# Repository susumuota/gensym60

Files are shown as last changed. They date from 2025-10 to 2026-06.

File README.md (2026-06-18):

# gensym60

A redesign of the symmetrical 60% keyboard.

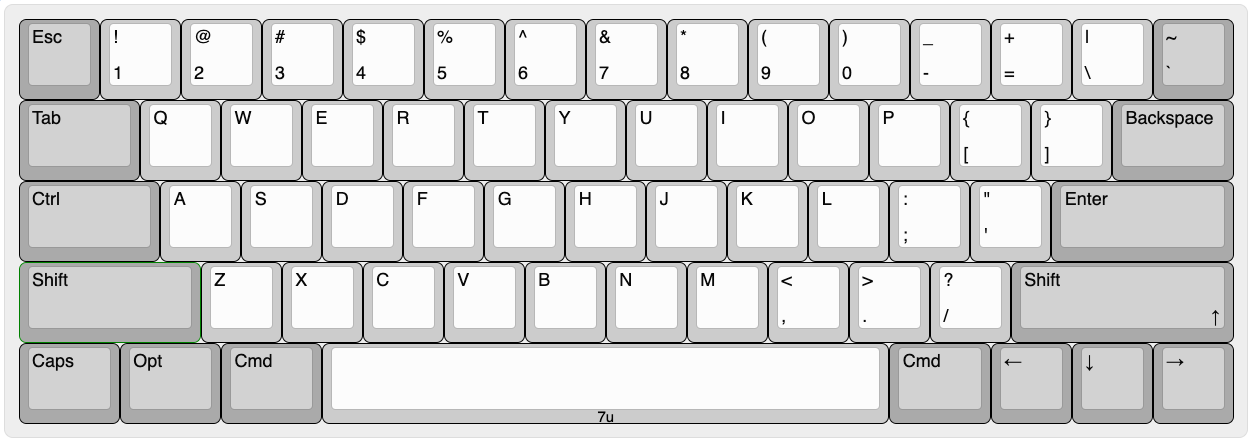
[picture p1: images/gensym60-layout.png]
layout


- 60% layout
- 7u space bar
- Split backspace
- Arrow keys (Up is mod-tap on the right shift)
- No split right shift

## Build firmware

```shell
git clone https://github.com/susumuota/gensym60.git

git clone https://github.com/vial-kb/vial-qmk.git
cd vial-qmk

# copy gensym60 directory to vial-qmk
rsync -av --delete ../gensym60/vial-qmk/keyboards/infinitemonkey/gensym60/ keyboards/infinitemonkey/gensym60/

RUNTIME="docker" SKIP_FLASHING_SUPPORT=1 util/docker_cmd.sh make infinitemonkey/gensym60:vial

ls -l infinitemonkey_gensym60_vial.bin
# -rwxr-xr-x 1 user group 37072 Jun 18 01:23 infinitemonkey_gensym60_vial.bin
```

## Flash firmware

Install `dfu-util` package.

```shell
brew install dfu-util
```

```shell
# unplug and plug the device pressing the dfu button
dfu-util -l
sudo dfu-util -a 0 -s 0x08000000:unprotect:force

# unplug and plug the device pressing the dfu button
dfu-util -l
sudo dfu-util -a 0 -s 0x08000000:mass-erase:force

# unplug and plug the device pressing the dfu button
dfu-util -l
sudo dfu-util -a 0 -s 0x08000000:leave -D infinitemonkey_gensym60_vial.bin
```

## References

- https://github.com/Unified-Daughterboard/UDB-C-JSH
- https://github.com/kkatano/bakeneko-60
- https://github.com/takishim/mikeneko65
- https://github.com/tominabox1/Le-Chiffre-Keyboard
- https://github.com/sporkus/le_chiffre_keyboard_stm32
- https://github.com/joe-scotto/scottokeebs/tree/main/Extras/ScottoModules/STM32F072CBT6
- https://www.st.com/resource/en/application_note/an4080-getting-started-with-stm32f0x1x2x8-hardware-development-stmicroelectronics.pdf
- https://www.st.com/en/evaluation-tools/32f072bdiscovery.html
- https://microfan.shop/products/stm32f072-mini-r1
- https://github.com/ShaneTWilliams/stm32-dev-board
- https://github.com/bennymeg/Fabrication-Toolkit
- https://github.com/Salicylic-acid3/KiCAD_FootPrint

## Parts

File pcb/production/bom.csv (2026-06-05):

Designator | Footprint | Quantity | Value | LCSC Part #
C1, C2, C9 | 0402 | 3 | 1u | C52923
C10, C12, C3, C4, C6, C7, C8 | 0402 | 7 | 100n | C1525
C11, C5 | 0402 | 2 | 4.7u | C23733
D1, D10, D11, D12, D13, D14, D15, D16, D17, D18, D19, D2, D20, D21, D22, D23, D24, D25, D26, D27, D28, D29, D3, D30, D31, D32, D33, D34, D35, D36, D37, D38, D39, D4, D40, D41, D42, D43, D44, D45, D46, D47, D48, D49, D5, D50, D51, D52, D53, D54, D55, D56, D57, D58, D59, D6, D60, D61, D62, D7, D8, D9 | D_SOD-123 | 62 | 1N4148W | C81598
F1 | 1206 | 1 | ASMD1206-050 | C135338
J1 | JST_SH_SM04B-SRSS-TB_1x04-1MP_P1.00mm_Horizontal | 1 | JST-SH | C160404
R1 | 0402 | 1 | 10k | C25744
SMDSW1 | SW_Push_1P1T_XKB_TS-1187A | 1 | TS-1187A-B-A-B | C318884
SW1, SW10, SW12, SW13, SW14, SW16, SW17, SW18, SW19, SW20, SW21, SW22, SW23, SW24, SW25, SW26, SW27, SW28, SW29, SW30, SW31, SW32, SW33, SW34, SW35, SW37, SW38, SW39, SW40, SW41, SW42, SW43, SW44, SW45, SW46, SW47, SW48, SW49, SW50, SW51, SW52, SW54, SW55, SW56, SW57, SW6, SW61, SW62, SW7, SW8, SW9 | CherryMX_Hotswap_1u | 51 | SW_Push | C41430893
SW11, SW15, SW5, SW53 | CherryMX_Hotswap_1.25u | 4 | SW_Push | C41430893
SW2, SW58 | CherryMX_Hotswap_1.5u | 2 | SW_Push | C41430893
SW3 | CherryMX_Hotswap_1.75u | 1 | SW_Push | C41430893
SW36 | CherryMX_Hotswap_7u_Rev | 1 | SW_Push | C41430893
SW4, SW59 | CherryMX_Hotswap_2.25u | 2 | SW_Push | C41430893
SW60 | CherryMX_Hotswap_2.75u | 1 | SW_Push | C41430893
U1 | SOT-23-3 | 1 | XC6206P332MR-G | C5446
U2 | LQFP-48_7x7mm_P0.5mm | 1 | STM32F072CBT6 | C81720
U3 | SOT-23-6 | 1 | USBLC6-2SC6 | C7519

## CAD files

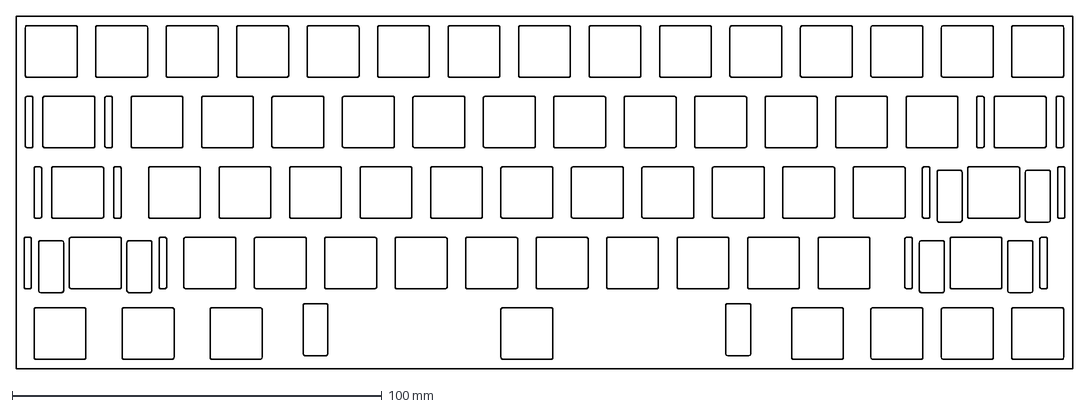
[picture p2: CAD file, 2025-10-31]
plate/gensym60_plate.dxf
285.8 x 95.2 mm

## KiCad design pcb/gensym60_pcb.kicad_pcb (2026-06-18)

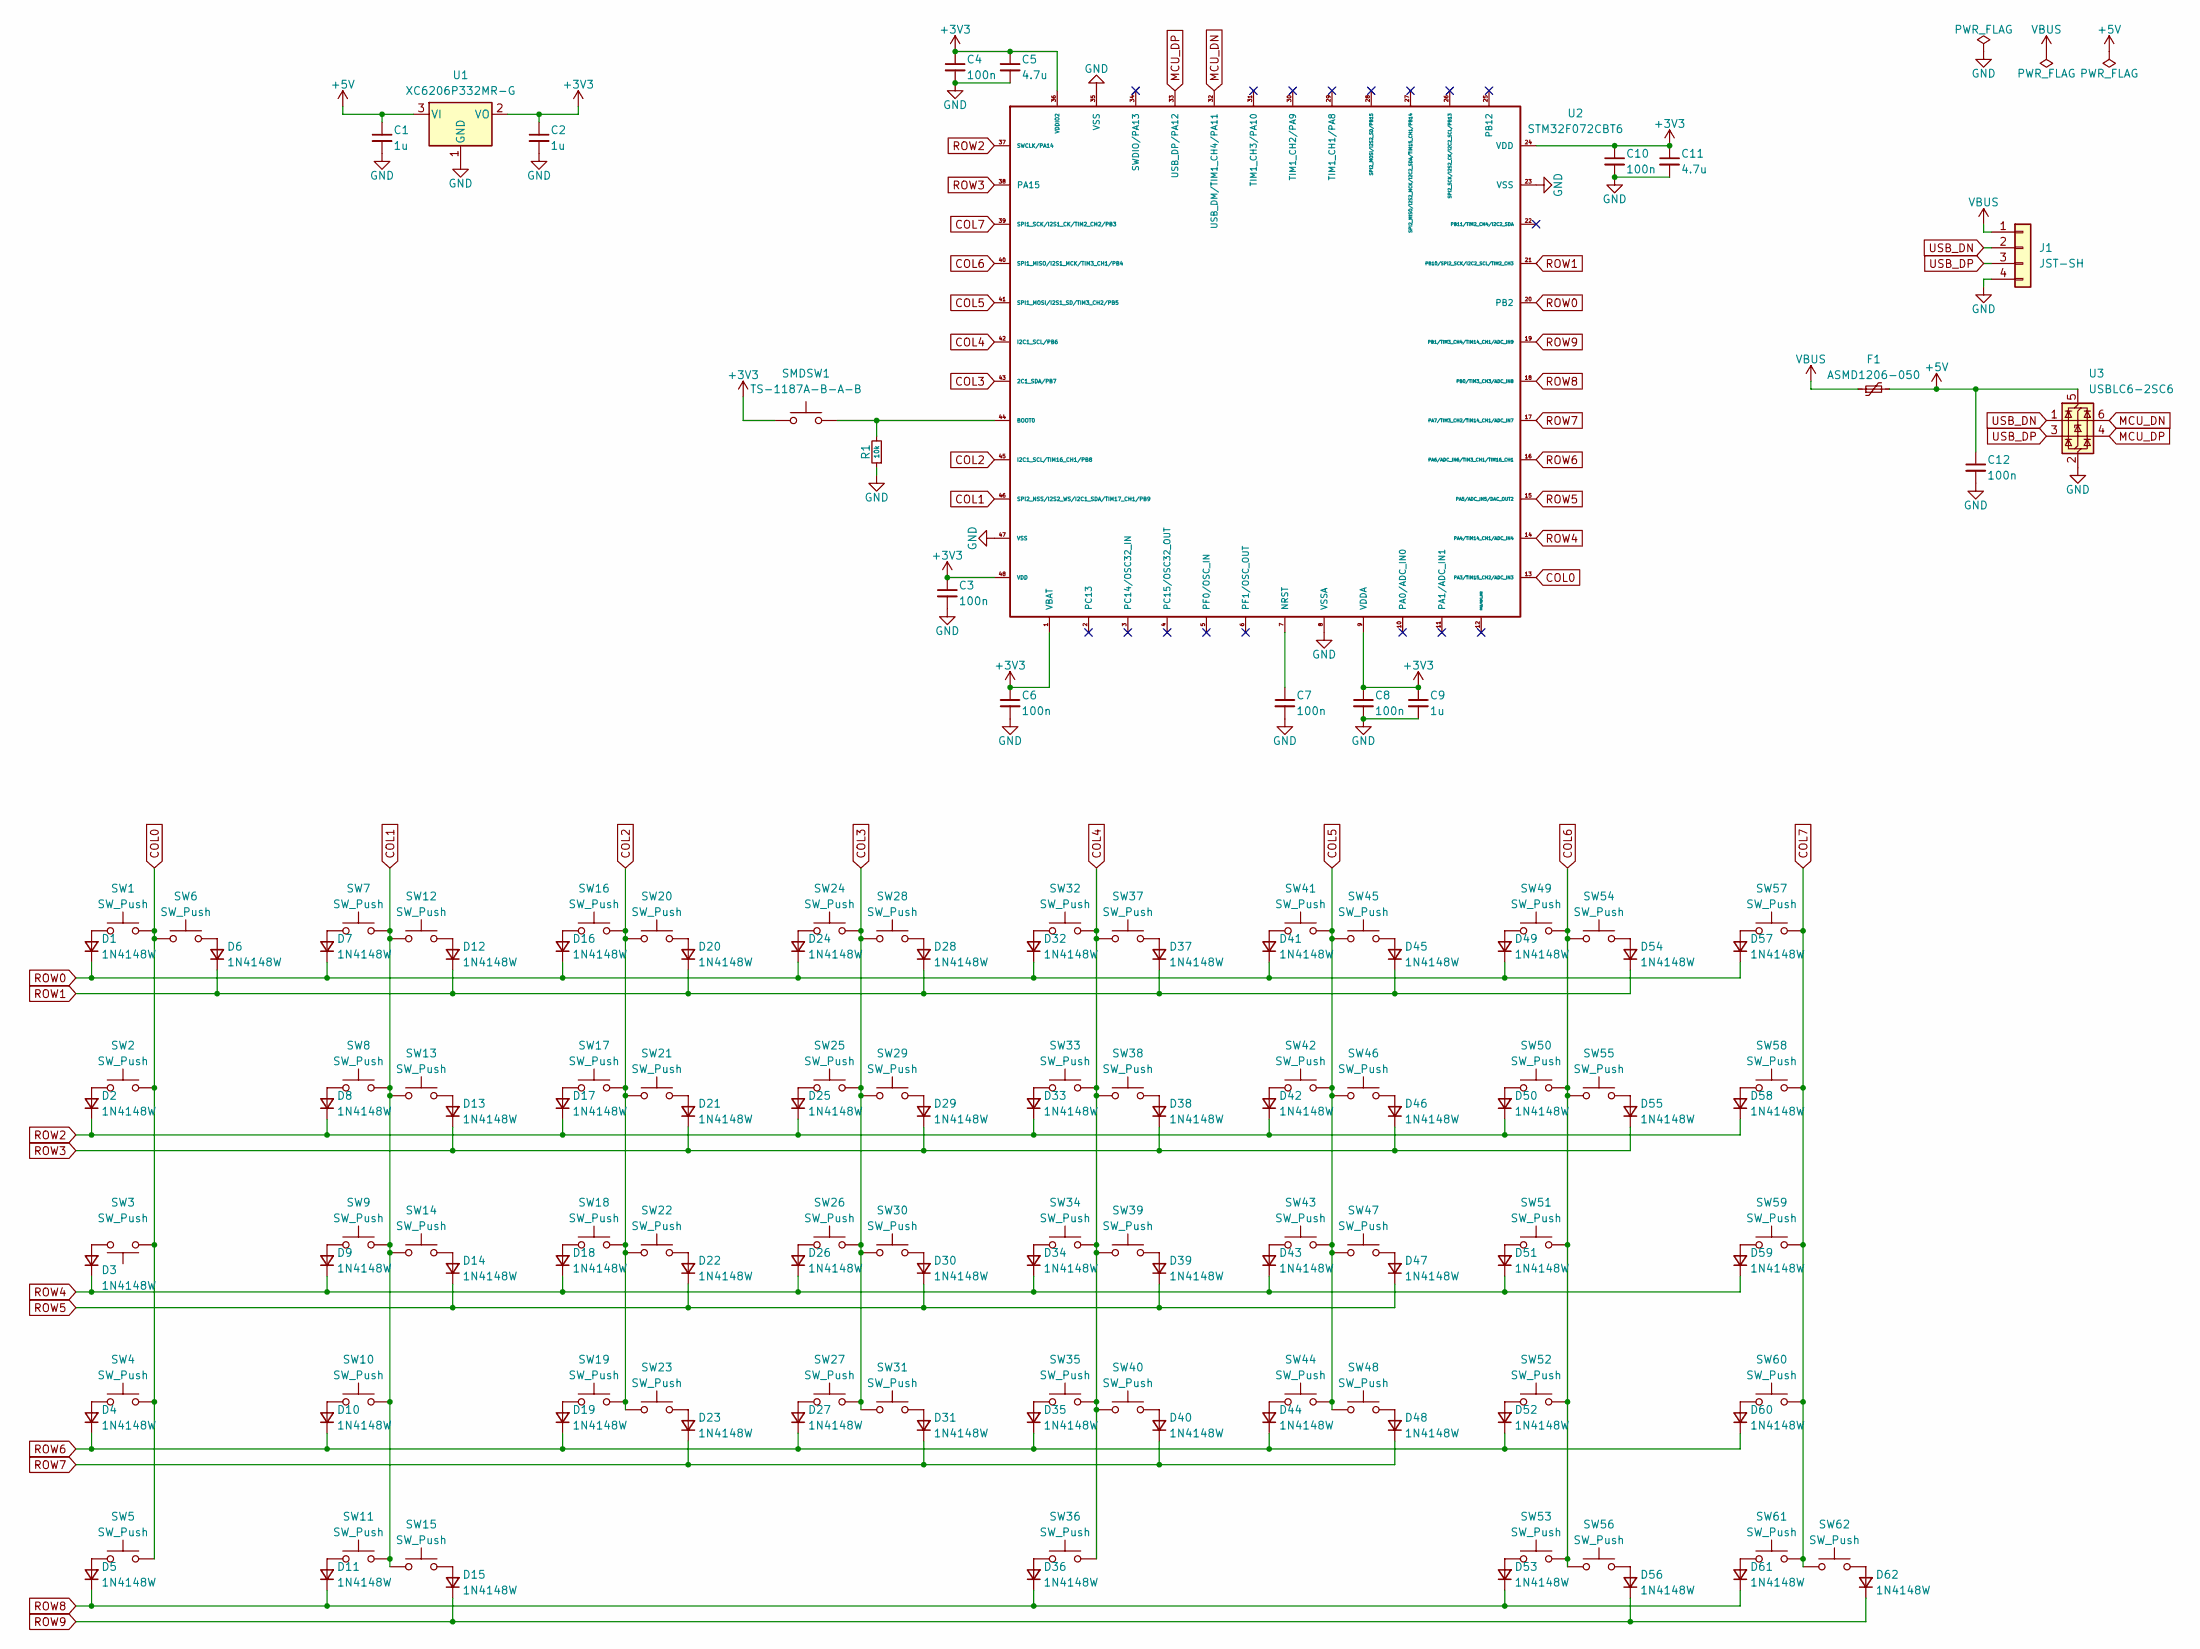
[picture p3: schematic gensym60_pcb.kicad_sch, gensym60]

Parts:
C1, C2, C9: 1u; C_0402_1005Metric; MFR.Part # CL05A105KA5NQNC; LCSC PN C52923
C3, C4, C6, C7, C8, C10, C12: 100n; C_0402_1005Metric; MFR.Part # CL05B104KO5NNNC; LCSC PN C1525
C5, C11: 4.7u; C_0402_1005Metric; MFR.Part # CL05A475MP5NRNC; LCSC PN C23733
D1, D2, D3, D4, D5, D6, D7, D8, D9, D10, D11, D12, D13, D14, D15, D16, D17, D18, D19, D20, D21, D22, D23, D24, D25, D26, D27, D28, D29, D30, D31, D32, D33, D34, D35, D36, D37, D38, D39, D40, D41, D42, D43, D44, D45, D46, D47, D48, D49, D50, D51, D52, D53, D54, D55, D56, D57, D58, D59, D60, D61, D62: 1N4148W; D_SOD-123; MFR.Part # 1N4148W; LCSC PN C81598
F1: ASMD1206-050; Fuse_1206_3216Metric; MFR.Part # ASMD1206-050; LCSC PN C135338
J1: JST-SH; JST_SH_SM04B-SRSS-TB_1x04-1MP_P1.00mm_Horizontal; MFR.Part # SM04B-SRSS-TB(LF)(SN); LCSC PN C160404
R1: 10k; R_0402_1005Metric; MFR.Part # 0402WGF1002TCE; LCSC PN C25744
SMDSW1: TS-1187A-B-A-B; SW_Push_1P1T_XKB_TS-1187A; MFR.Part # TS-1187A-B-A-B; LCSC PN C318884
SW1, SW6, SW7, SW8, SW9, SW10, SW12, SW13, SW14, SW16, SW17, SW18, SW19, SW20, SW21, SW22, SW23, SW24, SW25, SW26, SW27, SW28, SW29, SW30, SW31, SW32, SW33, SW34, SW35, SW37, SW38, SW39, SW40, SW41, SW42, SW43, SW44, SW45, SW46, SW47, SW48, SW49, SW50, SW51, SW52, SW54, SW55, SW56, SW57, SW61, SW62: SW_Push; CherryMX_Hotswap_1u; MFR.Part # CPG151101S11-16; LCSC PN C41430893
SW2, SW58: SW_Push; CherryMX_Hotswap_1.5u; MFR.Part # CPG151101S11-16; LCSC PN C41430893
SW3: SW_Push; CherryMX_Hotswap_1.75u; MFR.Part # CPG151101S11-16; LCSC PN C41430893
SW4, SW59: SW_Push; CherryMX_Hotswap_2.25u; MFR.Part # CPG151101S11-16; LCSC PN C41430893
SW5, SW11, SW15, SW53: SW_Push; CherryMX_Hotswap_1.25u; MFR.Part # CPG151101S11-16; LCSC PN C41430893
SW36: SW_Push; CherryMX_Hotswap_7u_Rev; MFR.Part # CPG151101S11-16; LCSC PN C41430893
SW60: SW_Push; CherryMX_Hotswap_2.75u; MFR.Part # CPG151101S11-16; LCSC PN C41430893
U1: XC6206P332MR-G; SOT-23-3; MFR.Part # XC6206P332MR-G; LCSC PN C5446
U2: STM32F072CBT6; LQFP-48_7x7mm_P0.5mm; MFR.Part # STM32F072CBT6; LCSC PN C81720
U3: USBLC6-2SC6; SOT-23-6; MFR.Part # USBLC6-2SC6; LCSC PN C7519

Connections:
+3V3: C2.1, C3.1, C4.1, C5.1, C6.1, C8.1, C9.1, C10.1, C11.1, SMDSW1.1, U1.2 (VO), U2.1 (VBAT), U2.9 (VDDA), U2.24 (VDD), U2.36 (VDDIO2), U2.48 (VDD)
+5V: C1.1, C12.1, F1.2, U1.3 (VI), U3.5 (VBUS)
COL0: SW1.2, SW2.2, SW3.1, SW4.2, SW5.2, SW6.1, U2.13 (PA3/TIM15_CH2/ADC_IN3)
COL1: SW7.2, SW8.2, SW9.2, SW10.2, SW11.2, SW12.1, SW13.1, SW14.1, SW15.1, U2.46 (SPI2_NSS/I2S2_WS/I2C1_SDA/TIM17_CH1/PB9)
COL2: SW16.2, SW17.2, SW18.2, SW19.2, SW20.1, SW21.1, SW22.1, SW23.1, U2.45 (I2C1_SCL/TIM16_CH1/PB8)
COL3: SW24.2, SW25.2, SW26.2, SW27.2, SW28.1, SW29.1, SW30.1, SW31.1, U2.43 (2C1_SDA/PB7)
COL4: SW32.2, SW33.2, SW34.2, SW35.2, SW36.2, SW37.1, SW38.1, SW39.1, SW40.1, U2.42 (I2C1_SCL/PB6)
COL5: SW41.2, SW42.2, SW43.2, SW44.2, SW45.1, SW46.1, SW47.1, SW48.1, U2.41 (SPI1_MOSI/I2S1_SD/TIM3_CH2/PB5)
COL6: SW49.2, SW50.2, SW51.2, SW52.2, SW53.2, SW54.1, SW55.1, SW56.1, U2.40 (SPI1_MISO/I2S1_MCK/TIM3_CH1/PB4)
COL7: SW57.2, SW58.2, SW59.2, SW60.2, SW61.2, SW62.1, U2.39 (SPI1_SCK/I2S1_CK/TIM2_CH2/PB3)
GND: C1.2, C2.2, C3.2, C4.2, C5.2, C6.2, C7.2, C8.2, C9.2, C10.2, C11.2, C12.2, J1.4, R1.1, U1.1 (GND), U2.8 (VSSA), U2.23 (VSS), U2.35 (VSS), U2.47 (VSS), U3.2 (GND)
MCU_DN: U2.32 (USB_DM/TIM1_CH4/PA11), U3.6 (I/O1)
MCU_DP: U2.33 (USB_DP/PA12), U3.4 (I/O2)
unnamed: D1.2 (A), SW1.1
unnamed: D2.2 (A), SW2.1
unnamed: D3.2 (A), SW3.2
unnamed: D4.2 (A), SW4.1
unnamed: D5.2 (A), SW5.1
unnamed: D6.2 (A), SW6.2
unnamed: D7.2 (A), SW7.1
unnamed: D8.2 (A), SW8.1
unnamed: D9.2 (A), SW9.1
unnamed: D10.2 (A), SW10.1
unnamed: D11.2 (A), SW11.1
unnamed: D12.2 (A), SW12.2
unnamed: D13.2 (A), SW13.2
unnamed: D14.2 (A), SW14.2
unnamed: D15.2 (A), SW15.2
unnamed: D16.2 (A), SW16.1
unnamed: D17.2 (A), SW17.1
unnamed: D18.2 (A), SW18.1
unnamed: D19.2 (A), SW19.1
unnamed: D20.2 (A), SW20.2
unnamed: D21.2 (A), SW21.2
unnamed: D22.2 (A), SW22.2
unnamed: D23.2 (A), SW23.2
unnamed: D24.2 (A), SW24.1
unnamed: D25.2 (A), SW25.1
unnamed: D26.2 (A), SW26.1
unnamed: D27.2 (A), SW27.1
unnamed: D28.2 (A), SW28.2
unnamed: D29.2 (A), SW29.2
unnamed: D30.2 (A), SW30.2
unnamed: D31.2 (A), SW31.2
unnamed: D32.2 (A), SW32.1
unnamed: D33.2 (A), SW33.1
unnamed: D34.2 (A), SW34.1
unnamed: D35.2 (A), SW35.1
unnamed: D36.2 (A), SW36.1
unnamed: D37.2 (A), SW37.2
unnamed: D38.2 (A), SW38.2
unnamed: D39.2 (A), SW39.2
unnamed: D40.2 (A), SW40.2
unnamed: D41.2 (A), SW41.1
unnamed: D42.2 (A), SW42.1
unnamed: D43.2 (A), SW43.1
unnamed: D44.2 (A), SW44.1
unnamed: D45.2 (A), SW45.2
unnamed: D46.2 (A), SW46.2
unnamed: D47.2 (A), SW47.2
unnamed: D48.2 (A), SW48.2
unnamed: D49.2 (A), SW49.1
unnamed: D50.2 (A), SW50.1
unnamed: D51.2 (A), SW51.1
unnamed: D52.2 (A), SW52.1
unnamed: D53.2 (A), SW53.1
unnamed: D54.2 (A), SW54.2
unnamed: D55.2 (A), SW55.2
unnamed: D56.2 (A), SW56.2
unnamed: D57.2 (A), SW57.1
unnamed: D58.2 (A), SW58.1
unnamed: D59.2 (A), SW59.1
unnamed: D60.2 (A), SW60.1
unnamed: D61.2 (A), SW61.1
unnamed: D62.2 (A), SW62.2
unnamed: R1.2, SMDSW1.2, U2.44 (BOOT0)
unnamed: C7.1, U2.7 (NRST)
ROW0: D1.1 (K), D7.1 (K), D16.1 (K), D24.1 (K), D32.1 (K), D41.1 (K), D49.1 (K), D57.1 (K), U2.20 (PB2)
ROW1: D6.1 (K), D12.1 (K), D20.1 (K), D28.1 (K), D37.1 (K), D45.1 (K), D54.1 (K), U2.21 (PB10/SPI2_SCK/I2C2_SCL/TIM2_CH3)
ROW2: D2.1 (K), D8.1 (K), D17.1 (K), D25.1 (K), D33.1 (K), D42.1 (K), D50.1 (K), D58.1 (K), U2.37 (SWCLK/PA14)
ROW3: D13.1 (K), D21.1 (K), D29.1 (K), D38.1 (K), D46.1 (K), D55.1 (K), U2.38 (PA15)
ROW4: D3.1 (K), D9.1 (K), D18.1 (K), D26.1 (K), D34.1 (K), D43.1 (K), D51.1 (K), D59.1 (K), U2.14 (PA4/TIM14_CH1/ADC_IN4)
ROW5: D14.1 (K), D22.1 (K), D30.1 (K), D39.1 (K), D47.1 (K), U2.15 (PA5/ADC_IN5/DAC_OUT2)
ROW6: D4.1 (K), D10.1 (K), D19.1 (K), D27.1 (K), D35.1 (K), D44.1 (K), D52.1 (K), D60.1 (K), U2.16 (PA6/ADC_IN6/TIM3_CH1/TIM16_CH1)
ROW7: D23.1 (K), D31.1 (K), D40.1 (K), D48.1 (K), U2.17 (PA7/TIM3_CH2/TIM14_CH1/ADC_IN7)
ROW8: D5.1 (K), D11.1 (K), D36.1 (K), D53.1 (K), D61.1 (K), U2.18 (PB0/TIM3_CH3/ADC_IN8)
ROW9: D15.1 (K), D56.1 (K), D62.1 (K), U2.19 (PB1/TIM3_CH4/TIM14_CH1/ADC_IN9)
USB_DN: J1.2, U3.1 (I/O1)
USB_DP: J1.3, U3.3 (I/O2)
VBUS: F1.1, J1.1

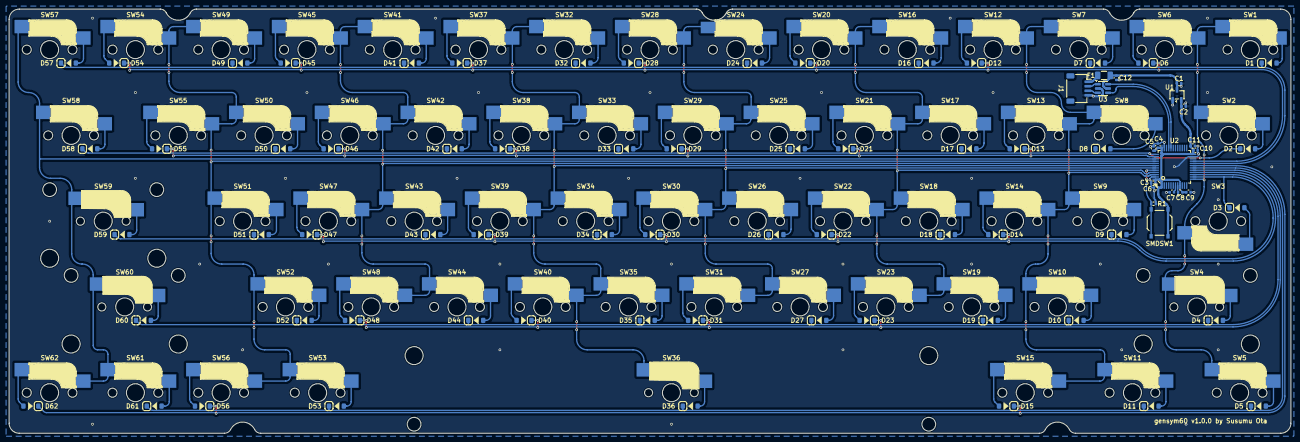
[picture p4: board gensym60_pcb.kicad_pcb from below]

Board: 2 copper layers, 284.7 x 94.2 mm, 143 parts (81 on the bottom side), 90 nets.

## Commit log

2025-10-20 feat: initial commit
    [gensym60_pcb.kicad_pcb, gensym60_pcb.kicad_sch]
2025-10-20 feat: add usb-c daughter board
    [gensym60_pcb.kicad_sch]
2025-10-20 feat: add key matrix
    [gensym60_pcb.kicad_sch]
2025-10-22 feat: place switches
    [gensym60_pcb.kicad_pcb, gensym60_pcb.kicad_sch]
2025-10-25 feat: connect switches
    [gensym60_pcb.kicad_pcb, gensym60_pcb.kicad_sch]
2025-10-26 feat: add fuse and esd
    [gensym60_pcb.kicad_pcb, gensym60_pcb.kicad_sch]
2025-10-31 feat: move mcu
    [gensym60_pcb.kicad_pcb]
2025-10-31 feat: add plate files
    [gensym60_plate.dxf, gensym60_plate.kicad_pcb, gensym60_plate.kicad_sch]
2025-12-06 feat: tweak design for production
    [gensym60_pcb.kicad_pcb, gensym60_pcb.kicad_sch]
2026-06-05 chore: add production fabrication outputs for ordering
    [bom.csv, positions.csv]
2026-06-16 chore: update plate fabrication files
2026-06-18 chore: standardize gensym60 naming
    [gensym60_pcb.kicad_pcb, gensym60_pcb.kicad_sch]
